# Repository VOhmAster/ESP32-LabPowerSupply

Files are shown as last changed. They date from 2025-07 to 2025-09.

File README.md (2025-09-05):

# ESP32 Lab Power Supply

DIY ESP32-based laboratory power supply with TFT display, rotary encoder, and OTA update.

##  Features
- Dual output (voltage and current control)
- TFT display (TFT_eSPI library)
- Rotary encoder control
- OTA firmware update
- Presets (3.3V, 5V, 7V) and customizable modes
- INA219 current measurement

##  Hardware
- ESP32 DevKit
- ILI9488 TFT display (3.5")
- SM-28BYJ-48-5V stepper motor x 2
- SM-ULN2003 stepper driver x 2
- INA219 current sensor x 2
- Rotary encoder
- LM2596S-PSUM module x 2
- SCT2650-STP-DWN module
- 40 x 40 12V fan

##  Setup
1. Install **ESP32 core** in Arduino IDE.
2. Install required libraries:
   - **TFT_eSPI** (for display)
   - **Adafruit INA219** (for current measurement)
   - **ArduinoOTA** (for OTA updates)
3. **Modify pin assignments in `User_Setup.h`** in the TFT_eSPI library folder to match your hardware configuration.
4. Set up your `User_Setup.h` for TFT.
5. Upload `LabPowerSupply.ino` to ESP32.

##  Recommended Pinout

Here is the recommended pin configuration for the ESP32 Lab Power Supply project. Please adjust the `User_Setup.h` file accordingly.

| Pin | Function | Description |
|---|---|---|
| GPIO 5  | Motor M1_IN1 | Motor driver input 1 for channel 1 |
| GPIO 19 | Motor M1_IN2 | Motor driver input 1 for channel 2 |
| GPIO 27 | Motor M1_IN3 | Motor driver input 1 for channel 3 |
| GPIO 33 | Motor M1_IN4 | Motor driver input 1 for channel 4 |
| GPIO 32 | Motor M2_IN1 | Motor driver input 2 for channel 1 |
| GPIO 25 | Motor M2_IN2 | Motor driver input 2 for channel 2 |
| GPIO 26 | Motor M2_IN3 | Motor driver input 2 for channel 3 |
| GPIO 14 | Motor M2_IN4 | Motor driver input 2 for channel 4 |
| GPIO 12 | Display LED | TFT display LED pin |
| GPIO 15 | Display CS | TFT display chip select |
| GPIO 2  | Display DC | TFT display data/command |
| GPIO 4  | Display RST | TFT display reset |
| GPIO 18 | Display CLK | TFT display clock (SPI SCK) |
| GPIO 23 | Display MOSI | TFT display data line (SPI MOSI) |
| GPIO 34 | Rotary Encoder A  | Rotary encoder signal A |
| GPIO 35 | Rotary Encoder B  | Rotary encoder signal B |
| GPIO 21 | INA219 SDA | INA219 sensor data line (I2C) |
| GPIO 22 | INA219 SCL | INA219 sensor clock line (I2C) |

> **Note:**  
> - This pinout is for the specific configuration used in this project.  
> - Modify the pins in the `User_Setup.h` file to fit your hardware setup.

### Hybrid Control System with Closed-Loop Feedback

This power supply uses a hybrid approach that combines **digital control** and **analog signal measurement**.  
The output voltage and current are continuously monitored through analog readings, while adjustments are performed digitally, resulting in more accurate control compared to systems that rely solely on digital signals.

The system operates with a **closed-loop feedback mechanism**, meaning it always uses the actual measured output values as the basis for regulation.  
This ensures stable and precise voltage and current control under varying load conditions.

### Open-Loop vs Closed-Loop Control

**Open-Loop (Without Feedback):**
Input Setpoint → [ Controller ] → Output  
(No real-time correction based on actual output)

**Closed-Loop (With Feedback):**
Input Setpoint → [ Controller ] → Output → [ Measurement ] → Feedback → [ Controller ]  
(The system continuously adjusts based on the actual measured values)

### Optional Bleeder Resistor for Smoother Voltage Adjustment

For more stable voltage adjustments, especially when fine-tuning the output voltage, it may be useful to add a bleeder resistor to the power supply circuit. This is optional and depends on your specific needs.

**Recommended Value:**
- **1 kΩ / 0.6 W** metal film resistor

## Demo

**Preset Switching:**  
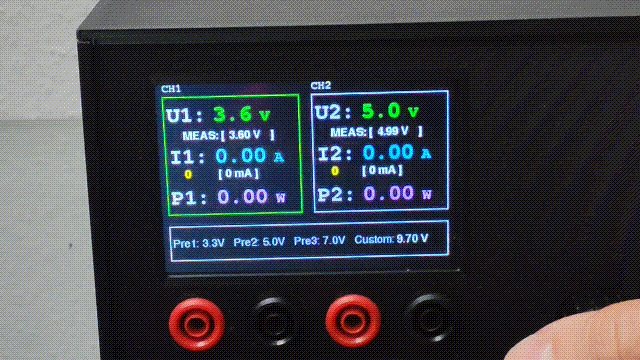
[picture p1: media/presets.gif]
Presets


**Load Response (Closed-loop feedback):**  
Load response

**Boot Sequence:**  
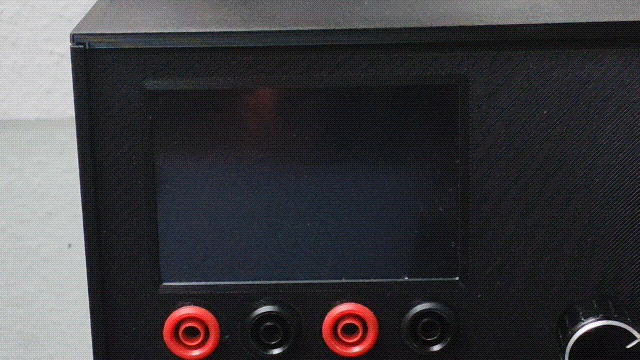
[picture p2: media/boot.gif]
Boot


**OTA Firmware Update:**  
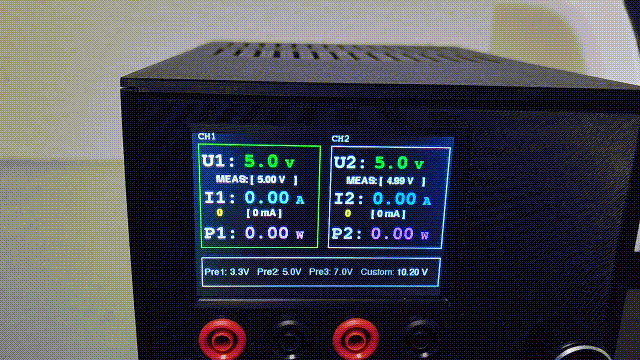
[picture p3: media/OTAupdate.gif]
OTA


I keep improving my projects and sharing everything for free. I really appreciate any support — it helps me buy parts and tools to make even better projects. You can support me here: [Ko-fi](https://ko-fi.com/vohmaster)

**Join my Discord server!**  
Click the invite link below to connect:  
[Discord Invite](https://discord.gg/2u2wJVqS)

## License
This project is licensed under the MIT License - see the [LICENSE](LICENSE) file for details.

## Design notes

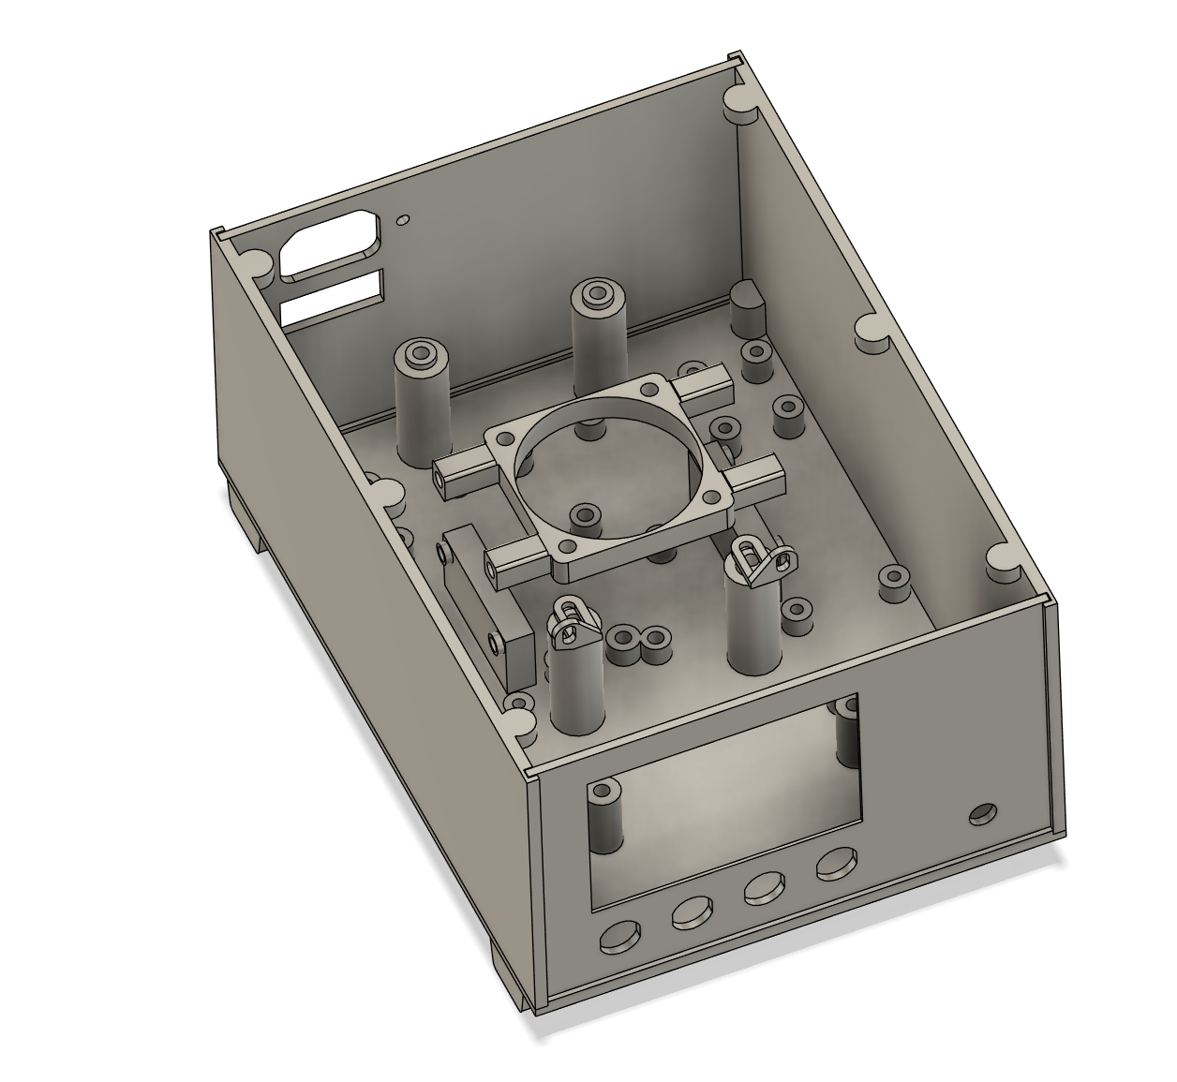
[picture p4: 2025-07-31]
images/Képernyőkép 2025-07-31 165328.png

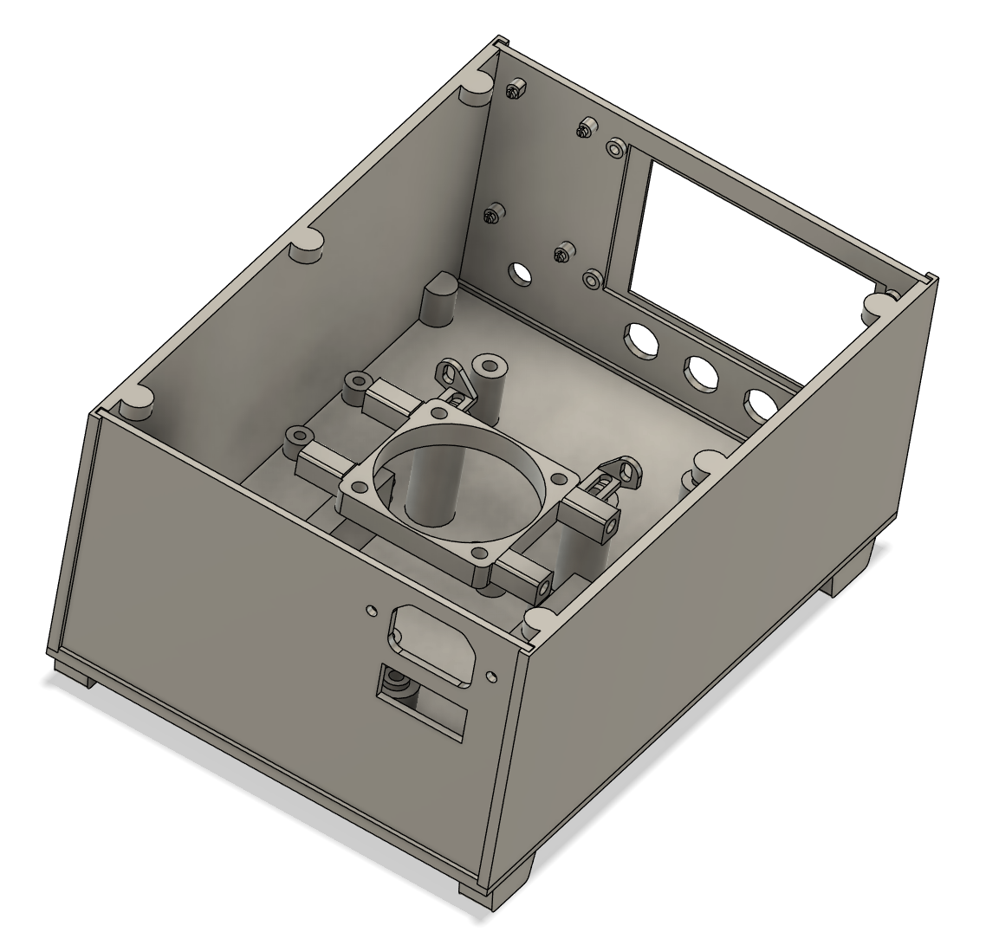
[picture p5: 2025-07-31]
images/Képernyőkép 2025-07-31 165347.png

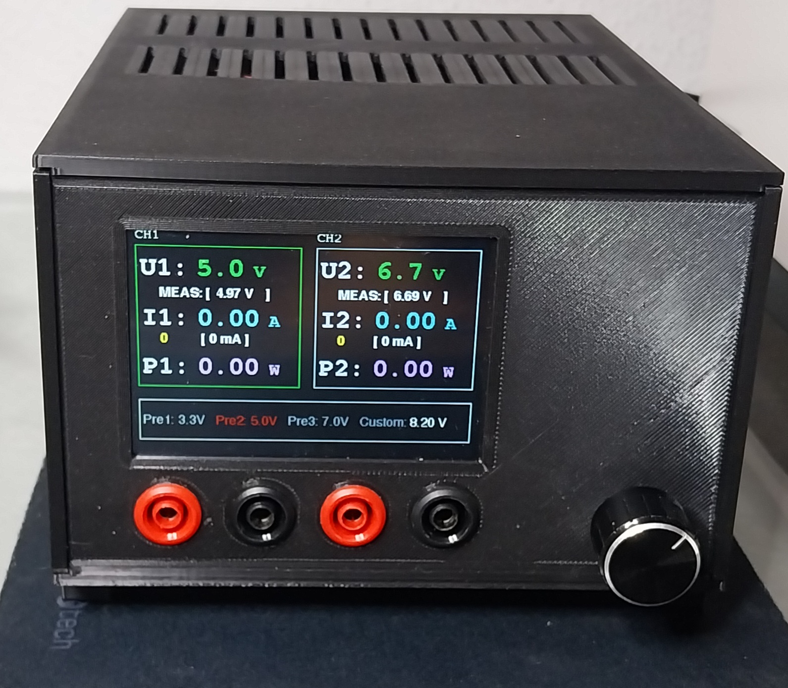
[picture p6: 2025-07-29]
images/labpowersupply.jpg

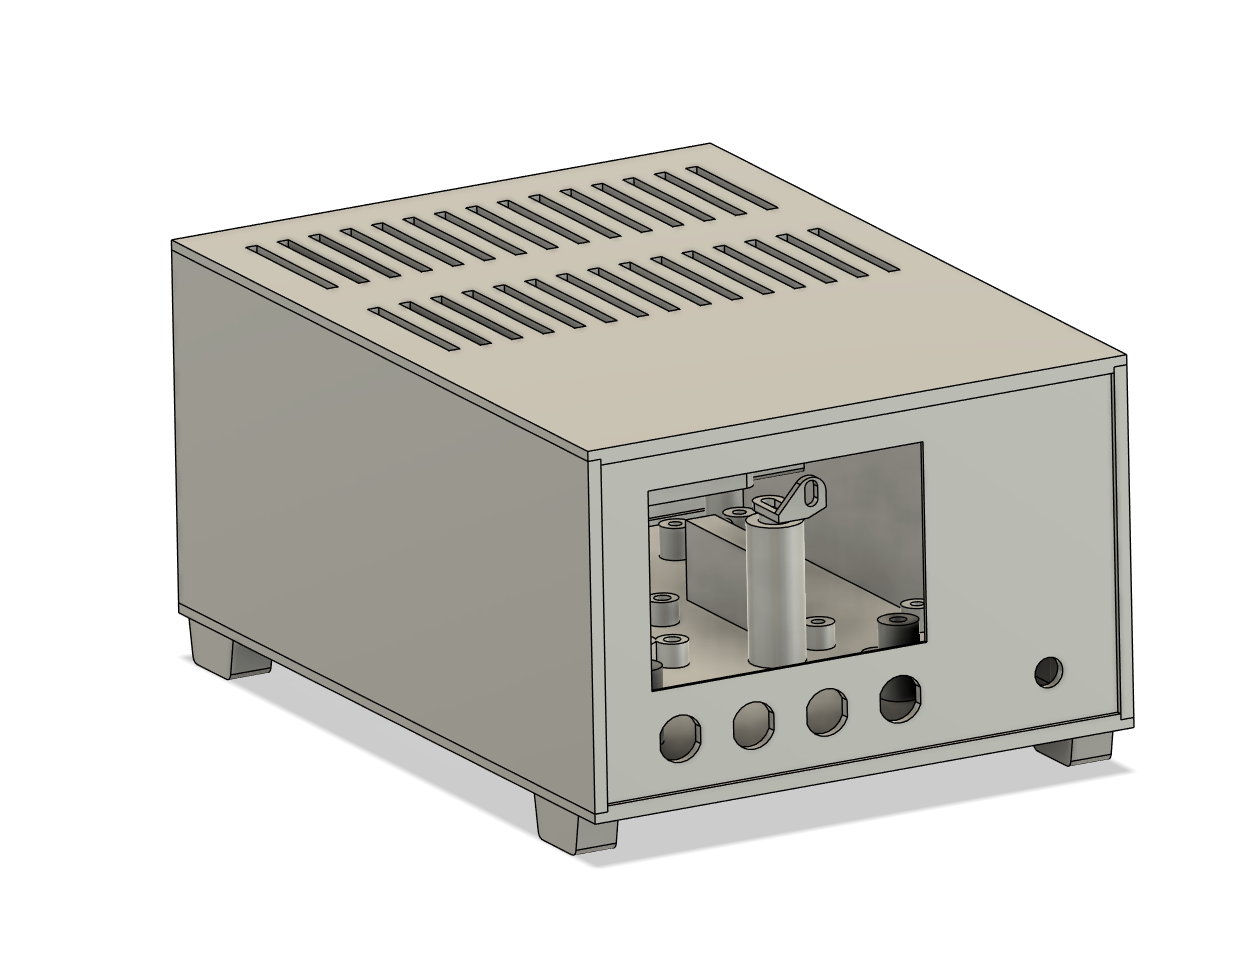
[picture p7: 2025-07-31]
images/Képernyőkép 2025-07-31 165406.png

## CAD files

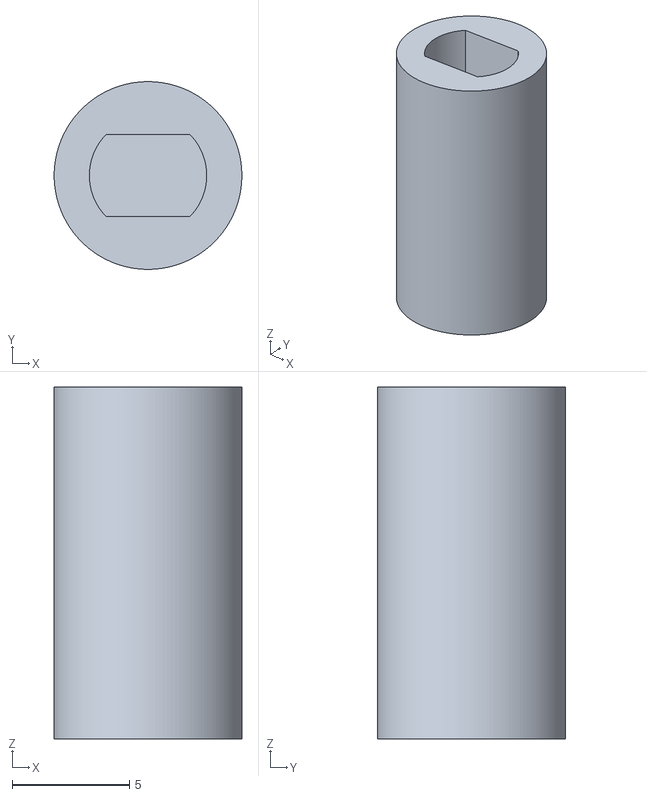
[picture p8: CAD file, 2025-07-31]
3D-models/shaft_coupling.stl
8.00 x 8.00 x 15.0

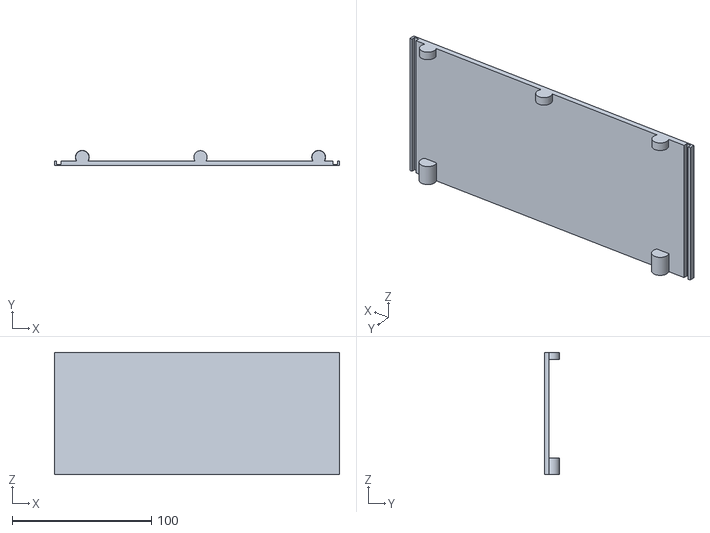
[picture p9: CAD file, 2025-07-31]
3D-models/right_panel.stl
205.0 x 11.0 x 88.0

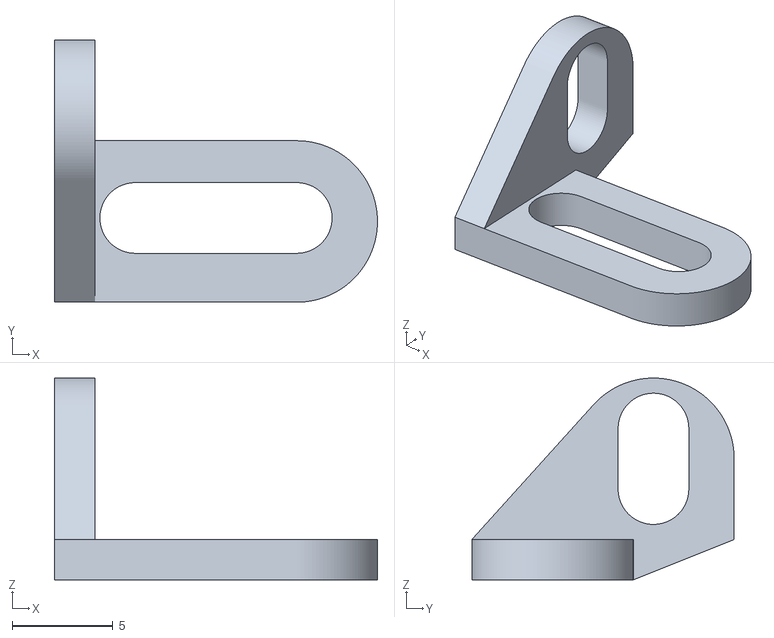
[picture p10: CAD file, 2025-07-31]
3D-models/right_bracket.stl
16.0 x 13.0 x 10.00

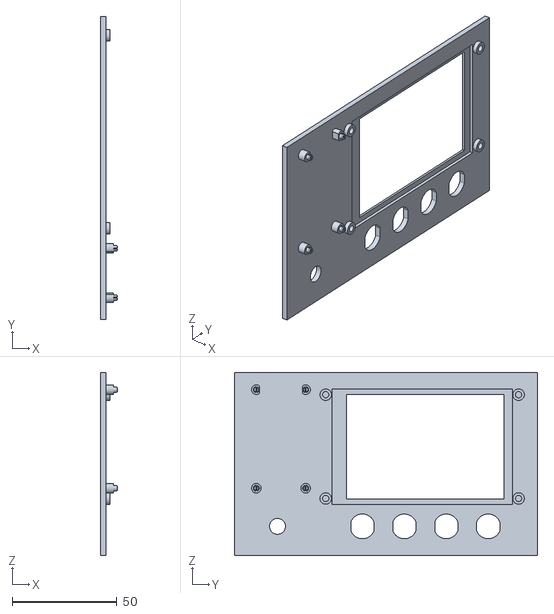
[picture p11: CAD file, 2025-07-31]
3D-models/fornt_panel.stl
7.90 x 144.5 x 87.5

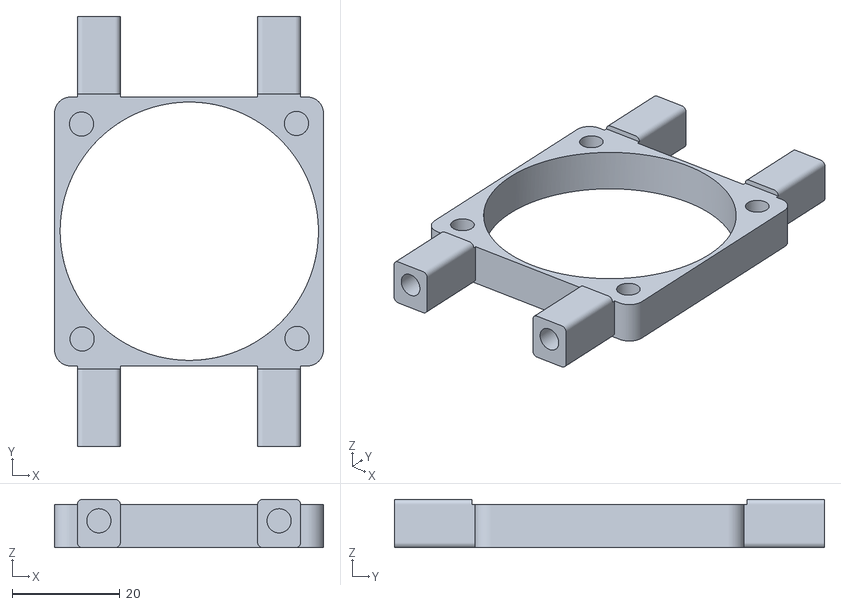
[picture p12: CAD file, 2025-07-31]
3D-models/fan_consol.stl
50.0 x 80.0 x 9.00

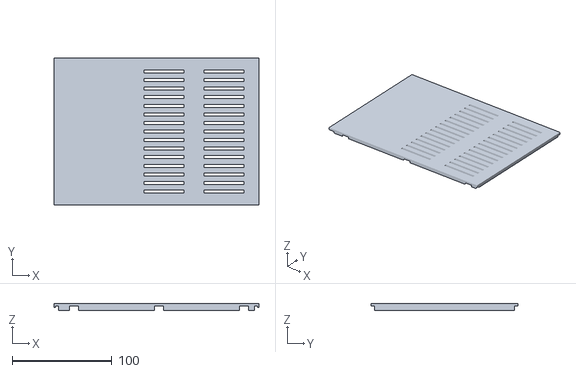
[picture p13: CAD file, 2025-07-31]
3D-models/cover.stl
205.0 x 147.0 x 7.00

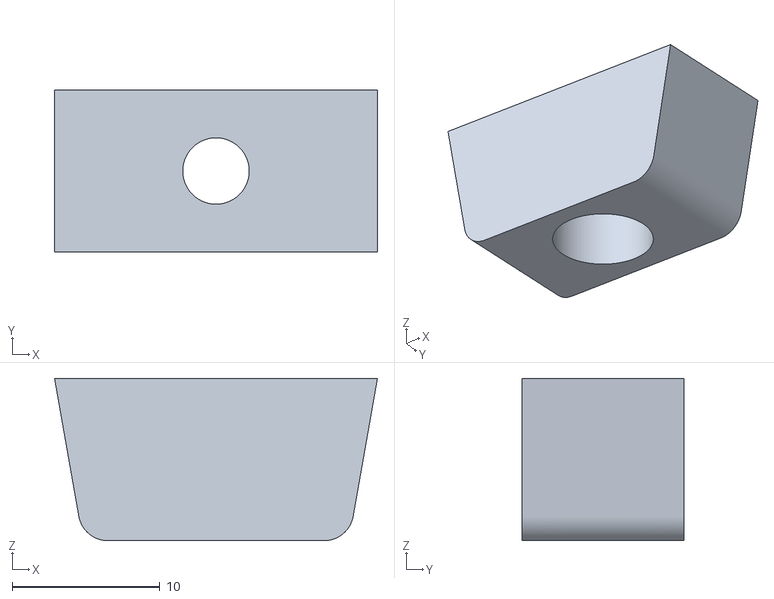
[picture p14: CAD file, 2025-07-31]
3D-models/Casefoot.stl
21.9 x 11.0 x 11.0

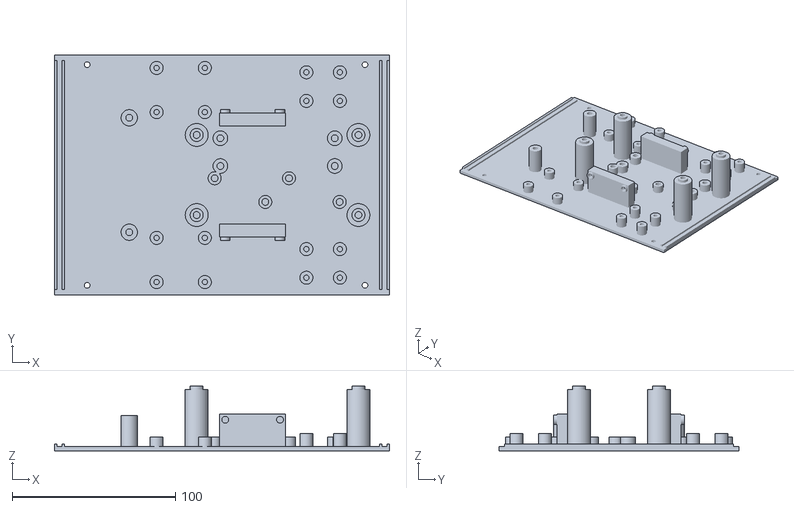
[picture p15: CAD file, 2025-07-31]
3D-models/bottom_panel.stl
205.0 x 147.0 x 39.5

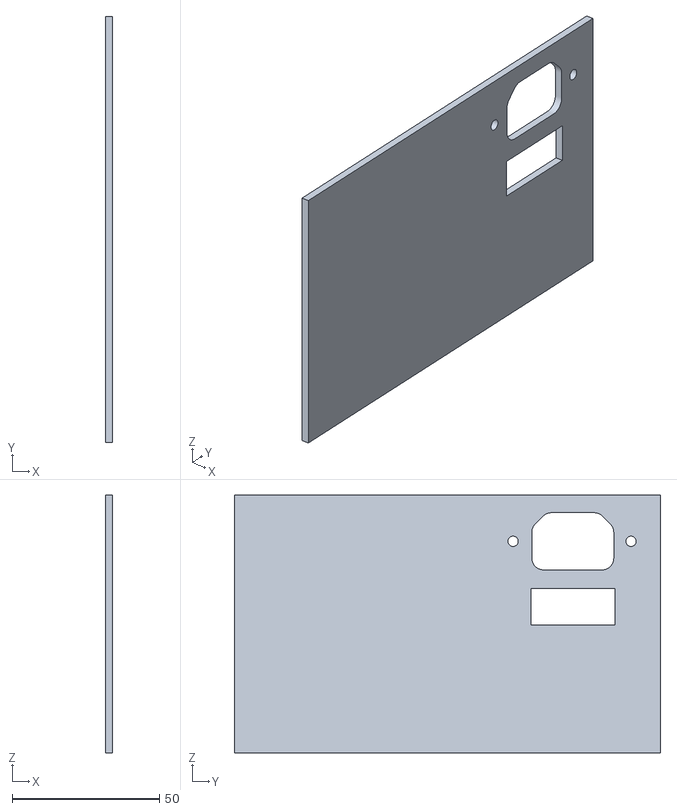
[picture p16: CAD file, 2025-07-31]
3D-models/back_panel.stl
2.50 x 144.5 x 87.5

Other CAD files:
3D-models/left_panel.stl
3D-models/left_bracket.stl

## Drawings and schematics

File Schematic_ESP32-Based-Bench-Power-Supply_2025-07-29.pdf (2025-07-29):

# TFT1 SD_SCK 18 SD_MISO ¹⁷

3 | 4 4V-40V Vin | 1.2V-36V Vout 4

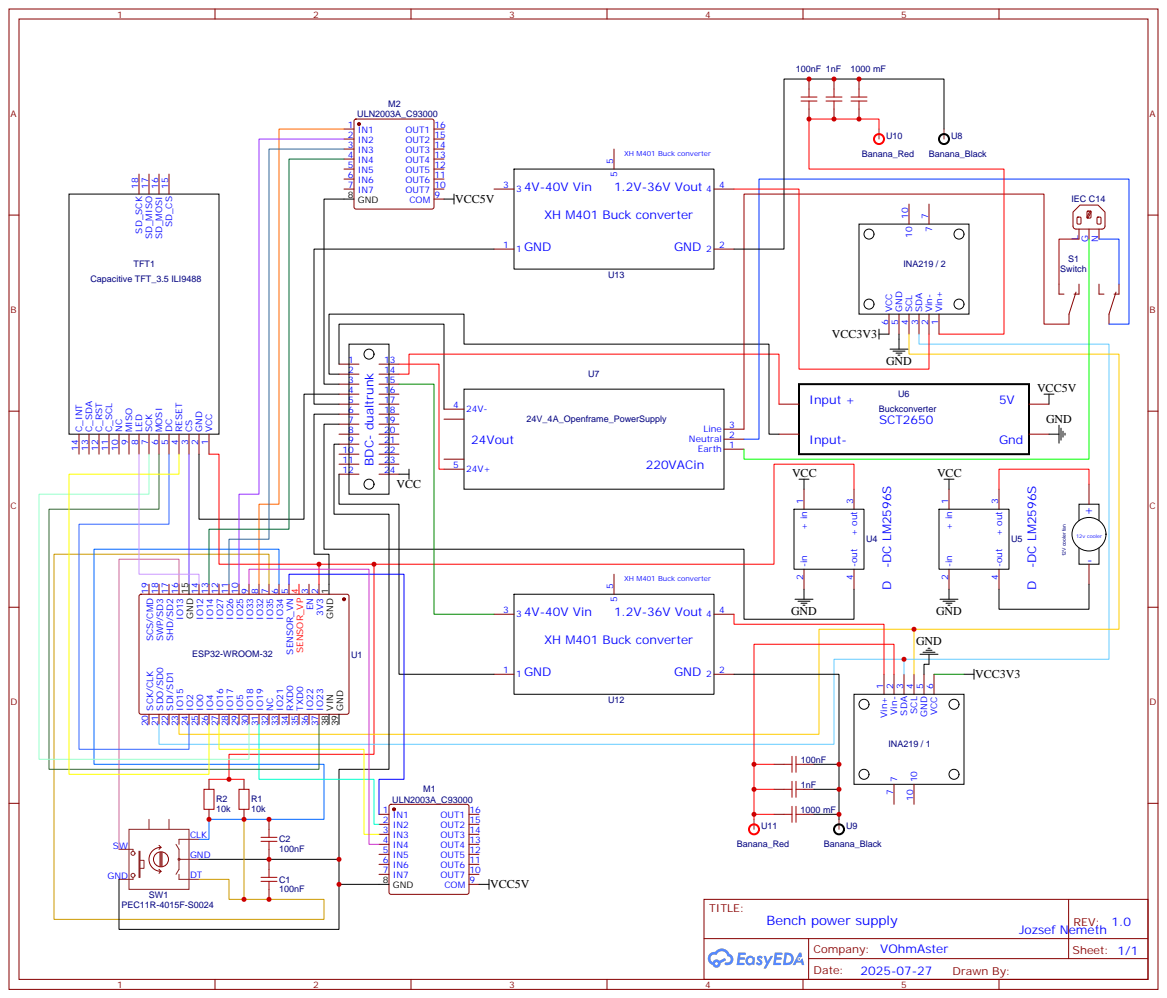
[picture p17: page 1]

9 IO25 10 IO26 11 IO27 12 IO14 13 IO12 14 GND 15 IO13 16 SHD/SD2 17 SWP/SD3 18 SCS/CMD 19 SCK/CLK 20 SDO/SD0 21 SDI/SD1 22 IO15 23 IO2 24 IO0 25 IO4 26 IO16 27 IO17 28 IO5 29 IO18 30

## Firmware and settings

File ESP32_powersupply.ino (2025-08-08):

#include <TFT_eSPI.h>
#include <SPI.h>
#include <ESP32Encoder.h>
#include <WiFi.h>
#include <ArduinoOTA.h>
#include "Free_Fonts.h" 
#include <string>
#include <Adafruit_INA219.h>
#include <Stepper.h>
#include <ESPmDNS.h>.
#include <EEPROM.h>

#define EEPROM_ADDR_PSET 0 

Adafruit_INA219 ina1(0x41);  // Default title
Adafruit_INA219 ina2(0x40);  // Second module with a different title

const char* ssid = "YOUR SSID";
const char* password = "YOUR PASSWORD";

// Variables for button handling
int presetIndex = 0;
bool buttonPressed = false;
unsigned long buttonPressStartTime = 0;
bool longPressHandled = false;
const unsigned long longPressDuration = 500; // Long button press duration
bool longPressMode = false;
bool inCustomPresetMode = false;

// presets
float presetVoltage;
float psetCustom = 0; // Starting value

// Define character color variables
uint16_t BGcolor;
uint16_t StandardColor;
uint16_t Out1Volt;
uint16_t Out2Volt;
uint16_t Out1Amper;
uint16_t Out2Amper;
uint16_t Out1Watt;
uint16_t Out2Watt;
uint16_t PsetI;
uint16_t PsetA;

TFT_eSPI tft = TFT_eSPI();

#define CLK 34
#define DT 35
#define SW  13
#define TFT_LED_PIN 12 

#define STEPS_PER_REV 2048
// Motor 1
#define M1_IN1 5
#define M1_IN2 19
#define M1_IN3 27
#define M1_IN4 33

// Motor 2
#define M2_IN1 32
#define M2_IN2 25
#define M2_IN3 26
#define M2_IN4 14

Stepper stepper1(STEPS_PER_REV, M1_IN1, M1_IN3, M1_IN2, M1_IN4);
Stepper stepper2(STEPS_PER_REV, M2_IN1, M2_IN3, M2_IN2, M2_IN4);

float value_U1 = 5;
float value_U2 = 5;

float globalOutV1 = 5;
float globalOutV2 = 5;

ESP32Encoder encoder;

float value = 2.5;
const float minValue = 1.5;
const float maxValue = 20.0;
const float step = 0.1;

long LastEncoderCount = 0;

unsigned long lastEncoderCheck = 0;
const unsigned long encoderInterval = 200;  // ms

unsigned long lastMeasurementTime = 0;
const unsigned long measurementInterval = 500; //ms

//float lastDisplayedValue = -1;
int voltageState = 1;

// Position of text lines
  int ULine = 60;
  int ILine = 130;
  int PLine = 200;

  int xs1pos = 15;
  int xs2pos = 255;
  int yspos = 20;
  int borderW = 220;

// Position of the preset menu

  int PrXpos = 15;
  int PrYpos = 240;


void setup() {
  delay(1000);
  Wire.begin();  
  Wire.setClock(400000);  
  Serial.begin(115200);

  EEPROM.begin(512);  

   float value;
  EEPROM.get(EEPROM_ADDR_PSET, value);
  if (value < 1.5 || value > 20.0) value = 2.5;
  psetCustom = value;

  pinMode(TFT_LED_PIN, OUTPUT);
  digitalWrite(TFT_LED_PIN, HIGH); 

  tft.init();
  tft.setRotation(1);

  // OUTPUT warning
  tft.fillScreen(BGcolor);
  tft.setCursor(10, 30);
  tft.setFreeFont(FF21);
  tft.setTextColor(TFT_YELLOW, BGcolor);
  tft.print("OUTPUT ACTIVE");
  tft.setCursor(10, 70);
  tft.print("WAIT FOR READY...");
  
  tft.setCursor(10, 110);   
  tft.setFreeFont(FM12);  
  tft.setTextColor(TFT_WHITE, BGcolor);  
  tft.print("Connection to WiFi");

  WiFi.begin(ssid, password);
  delay(500);

  unsigned long startAttemptTime = millis();  

int XDot = 10;
while (WiFi.status() != WL_CONNECTED && millis() - startAttemptTime < 10000) { 
  delay(500);
  Serial.print(".");
  tft.setCursor(XDot, 140);
  XDot += 12;
  tft.print(".");
}

if (WiFi.status() == WL_CONNECTED) {
 
  tft.setCursor(10, 170);
  tft.print("WiFi connected!");
  delay(2000);
  setupOTA();  
} else {
  
  tft.setCursor(10, 170);
  tft.print("WiFi connection failed!");
  tft.setCursor(10, 200);
  tft.print("Continuing without OTA...");
  delay(2000);
}
    
  tft.setFreeFont(FM12);
if (!ina1.begin()) {
  
  tft.setCursor(10, 240);
  tft.setTextColor(TFT_RED); 
  tft.print("INA219 #1 not detected!");
  delay(2000);
  while (1);
} else {
  
  tft.setCursor(10, 240);
  tft.setTextColor(TFT_GREEN); 
  tft.print("INA219 #1 detected.");
  delay(2000);
}
ina1.setCalibration_32V_2A();

if (!ina2.begin()) {
 
  tft.setCursor(10, 280);
  tft.setTextColor(TFT_RED);
  tft.print("INA219 #2 not detected!");
  delay(2000);
  while (1);
} else {
  tft.setCursor(10, 280);
  tft.setTextColor(TFT_GREEN);
  tft.print("INA219 #2 detected.");
  delay(2000);
}
ina2.setCalibration_32V_2A();
  
  stepper1.setSpeed(8);
  stepper2.setSpeed(8);

   
  pinMode(SW, INPUT_PULLUP);

  encoder.attachHalfQuad(DT, CLK);
      
    // Color definitions
 
BGcolor = tft.color565(0, 0, 0);
StandardColor = tft.color565(232, 228, 227);
Out1Volt= tft.color565(65, 227, 20);
Out2Volt= tft.color565(65, 227, 20);
Out1Amper= tft.color565(158, 230, 226);
Out2Amper= tft.color565(158, 230, 226);
Out1Watt= tft.color565(237, 161, 232);
Out2Watt= tft.color565(237, 161, 232);
PsetI= tft.color565(171, 168, 167);
PsetA= tft.color565(217, 23, 9);


// Font definitions

#define StandardFont &FreeMonoBold18pt7b
#define measText &FreeMonoBold12pt7b

  tft.fillScreen(BGcolor);
  
  // Menu structure setup

  tft.setCursor(xs1pos, 10);   
  tft.setFreeFont(FM9);  
  tft.setTextColor(TFT_WHITE, BGcolor);  
  tft.print("CH1");
  tft.setCursor(xs2pos, 10);
  tft.print("CH2");
   
  // Left and right frame
  tft.drawRect(xs1pos, yspos, borderW, 200, TFT_GREEN);
  tft.drawRect(xs2pos, yspos, borderW, 200, TFT_WHITE);

 // Preset menu frame
   tft.drawRect(PrXpos, PrYpos, 460, 60, TFT_WHITE);

 // Preset texts
  tft.setCursor(PrXpos + 5, PrYpos +35);   
  tft.setFreeFont(FSS9);  
  tft.setTextColor(PsetI, BGcolor);  
  tft.print("Pre1: 3.3V   ");
  tft.print("Pre2: 5.0V   ");
  tft.print("Pre3: 7.0V   ");
  tft.print("Custom:");
  char bufferSet[20];
  sprintf(bufferSet, "%.2f V", psetCustom);
  tft.setCursor(PrXpos + 375, PrYpos + 35);   
  tft.setFreeFont(FSS9);  
  tft.setTextColor(TFT_WHITE, BGcolor);  
  tft.print(bufferSet);

  
voltageState = 1;
while (abs(ina1.getBusVoltage_V() - globalOutV1) > 0.05) {
  regulateOutputVoltageCH1();
  delay(2); 
}
drawVoltage(value_U1);

voltageState = 2;
while (abs(ina2.getBusVoltage_V() - globalOutV2) > 0.05) {
  regulateOutputVoltageCH2();
  delay(2); 
}
drawVoltage(value_U2);

encoder.setCount((int)(value_U1 / step) * 2);
voltageState = 1;

    tft.setFreeFont(FF21);
    tft.setTextColor(TFT_WHITE, BGcolor);
    tft.setCursor(xs1pos+30, ULine + 30);
    tft.print("MEAS: [               ]");
    tft.setCursor(xs2pos+30, ULine + 30);
    tft.print("MEAS: [               ]");

}

void setupOTA() {
  ArduinoOTA.setHostname("esp32-tap");
  static std::string Oldpercent = "";

  ArduinoOTA.onStart([]() {
    tft.fillScreen(BGcolor); 
    tft.setFreeFont(FF21);
    tft.setTextColor(StandardColor, BGcolor);
    tft.setCursor(10, 30);
    tft.print("OTA: update starting...");
  });

  ArduinoOTA.onProgress([](unsigned int progress, unsigned int total) {
    char buffer[32];
    tft.setCursor(10, 80);
    tft.setFreeFont(FF18);
    tft.print("Progress :");
    sprintf(buffer, "%3u %%", (progress * 100) / total);
    tft.setCursor(105, 80);
    tft.setTextColor(TFT_BLACK, BGcolor);
    tft.print(Oldpercent.c_str());
    tft.setCursor(105, 80);
    tft.setTextColor(TFT_LIGHTGREY, BGcolor);
    tft.print(buffer);

    Oldpercent = std::string(buffer);
  });

  ArduinoOTA.onEnd([]() {
    tft.fillRect(0, 90, 480, 40, BGcolor);
    tft.setCursor(10, 120);
    tft.setFreeFont(FF21);
    tft.setTextColor(TFT_GREEN, BGcolor);
    tft.print("Update complete.");
  });

  ArduinoOTA.onError([](ota_error_t error) {
    tft.fillRect(0, 90, 480, 60, BGcolor);
    tft.setCursor(10, 120);
    tft.setFreeFont(FF21);
    tft.setTextColor(TFT_RED, BGcolor);
    tft.print("OTA hiba: ");
    switch (error) {
      case OTA_AUTH_ERROR: tft.print("Auth"); break;
      case OTA_BEGIN_ERROR: tft.print("Begin"); break;
      case OTA_CONNECT_ERROR: tft.print("Connect"); break;
      case OTA_RECEIVE_ERROR: tft.print("Receive"); break;
      case OTA_END_ERROR: tft.print("End"); break;
      default: tft.print("Unknown"); break;
    }
  });

  ArduinoOTA.begin();
}

void loop() {
  unsigned long currentTime = millis();

  if (currentTime - lastMeasurementTime >= measurementInterval) {
    lastMeasurementTime = currentTime;
    drawMeasuredVoltage(); 
    drawAmper();
    drawWatt();
  }

 

    // Only handle the encoder and short press in normal mode
  if (!longPressMode) {

    // Select active voltage variable (with reference)
    float& activeValue = (voltageState == 1) ? value_U1 : value_U2;

   // Get raw encoder value (interpreted as step count)
    int encSteps = encoder.getCount() / 2;
    float newValue = encSteps * step;

    // Handle boundaries
    if (newValue < minValue) {
        newValue = minValue;
        encoder.setCount((int)(minValue / step) * 2);
    } else if (newValue > maxValue) {
        newValue = maxValue;
        encoder.setCount((int)(maxValue / step) * 2);
    }

    activeValue = newValue;
    drawVoltage(activeValue);
}

 unsigned long currentMillis = millis();
  if (currentMillis - lastEncoderCheck >= encoderInterval) {
    lastEncoderCheck = currentMillis;

    
    int buttonState = digitalRead(SW);

    if (buttonState == LOW) {
      if (!buttonPressed) {
        buttonPressed = true;
        buttonPressStartTime = currentMillis;
        longPressHandled = false;
      } else {
        if (!longPressHandled && (currentMillis - buttonPressStartTime >= longPressDuration)) {
          longPressHandled = true;
          longPressMode = !longPressMode; 
          if (longPressMode) {
             inCustomPresetMode = false;
             presetIndex = 0;  
            applyPreset(presetIndex);
            drawPresetMenu(presetIndex);

          } else {
            exitLongPressMode();

          }
        }
      }
    } else {
      if (buttonPressed) {
        if (!longPressHandled && !longPressMode) {
          voltageState = (voltageState == 1) ? 2 : 1;
          float encoderValue = (voltageState == 1) ? value_U1 : value_U2;
          encoder.setCount((int)(encoderValue / step) * 2);

      if (voltageState == 1) {
        // Change frame colors to the active channel
        tft.drawRect(xs1pos, yspos, borderW, 200, TFT_GREEN);  
        tft.drawRect(xs2pos, yspos, borderW, 200, TFT_WHITE);  
      } else {
        
        tft.drawRect(xs1pos, yspos, borderW, 200, TFT_WHITE);  
        tft.drawRect(xs2pos, yspos, borderW, 200, TFT_GREEN);  
      }


        }
        buttonPressed = false;
      }
    }
  }

  if (longPressMode) {
  if (inCustomPresetMode) {
    handleCustomPreset(); 
  } else {
    handleLongPressMode(); 
  }
}

  regulateOutputVoltageCH1();
  regulateOutputVoltageCH2();
  ArduinoOTA.handle();
}


void enterLongPressMode() {
  
  // Entered long press mode
 
  tft.drawRect(PrXpos, PrYpos, 460, 60, TFT_GREEN);
  presetIndex = 0;
  applyPreset(presetIndex);
  
}

void exitLongPressMode() {
  encoder.attachHalfQuad(DT, CLK);
  encoder.setCount(LastEncoderCount * 2);   
  // Exited long press mode
  // Redraw preset bar with inactive color
  tft.setCursor(PrXpos + 5, PrYpos + 35);   
  tft.setFreeFont(FSS9);  

  tft.setTextColor(PsetI, BGcolor);  
  tft.print("Pre1: 3.3V   ");

  tft.setTextColor(PsetI, BGcolor);  
  tft.print("Pre2: 5.0V   ");

  tft.setTextColor(PsetI, BGcolor);  
  tft.print("Pre3: 7.0V   ");

  tft.setTextColor(PsetI, BGcolor);  
  tft.print("Custom:");

  tft.drawRect(PrXpos, PrYpos, 460, 60, TFT_WHITE);
  if (voltageState == 1){
    globalOutV1 = presetVoltage;
  tft.drawRect(xs2pos, yspos, borderW, 200, TFT_WHITE); 
  tft.drawRect(xs1pos, yspos, borderW, 200, TFT_GREEN); 
   
  }else{
     globalOutV2 = presetVoltage;
  tft.drawRect(xs1pos, yspos, borderW, 200, TFT_WHITE); 
  tft.drawRect(xs2pos, yspos, borderW, 200, TFT_GREEN); 
   
   }
  drawVoltage(presetVoltage);
  
  }

void handleLongPressMode() {
  
  if (inCustomPresetMode) {
    handleCustomPreset();
    return;  
  }

  int buttonState = digitalRead(SW);
  encoder.detach(); 
  if (buttonState == LOW) {
  if (!buttonPressed) {
    buttonPressed = true;
    buttonPressStartTime = millis();
    longPressHandled = false;
  }
} else {
  if (buttonPressed) {
    unsigned long pressDuration = millis() - buttonPressStartTime;
    if (pressDuration < longPressDuration) {
      // Switch preset on button press

      presetIndex = (presetIndex + 1) % 4;

      if (presetIndex == 3) {
        inCustomPresetMode = true;
        drawPresetMenu(3);
      } else {
        inCustomPresetMode = false;
        applyPreset(presetIndex);
        drawPresetMenu(presetIndex);
      }
    }
    buttonPressed = false;
  }
}
}

void drawPresetMenu(int activeIndex) {
  tft.setCursor(PrXpos + 5, PrYpos + 35);
  tft.setFreeFont(FSS9);

  for (int i = 0; i < 4; i++) {
    if (i == activeIndex) {
      tft.setTextColor(PsetA, BGcolor);  // Active color
    } else {
      tft.setTextColor(PsetI, BGcolor);  // Inactive color
    }

    switch (i) {
      case 0:
        tft.print("Pre1: 3.3V   ");
        break;
      case 1:
        tft.print("Pre2: 5.0V   ");
        break;
      case 2:
        tft.print("Pre3: 7.0V   ");
        break;
      case 3:
        tft.print("Custom:");
        break;
    }
  }
}

void applyPreset(int index) {
       encoder.detach(); 
  switch (index) {
    case 0:
      presetVoltage = 3.3;
      LastEncoderCount = 33;
     break;
    case 1:
      presetVoltage = 5.0;
      LastEncoderCount = 50;
      break;
    case 2:
      presetVoltage = 7.0;
      LastEncoderCount = 70;
      break;
    default:
      
      presetVoltage = psetCustom; 
      LastEncoderCount = psetCustom * 10;
      break;  
  }

 // Set the voltage value to the corresponding channel
  if (voltageState == 1) {
    globalOutV1 = presetVoltage;
  } else {
    globalOutV2 = presetVoltage;
  }
  drawVoltage(presetVoltage);
}

void handleCustomPreset() {
  encoder.attachHalfQuad(DT, CLK);
  static long lastCount = 0;
  static bool initialized = false;
  static std::string OldpsetCustom = "";

  if (!initialized) {
  initialized = true;

  // psetCustom retrieved from EEPROM has already been set previously

  long rawCount = (psetCustom) / 0.1;
  //Limits of adjustment with the encoder.

  if (rawCount < 15) rawCount = 15; // 15 = 1.5V
  else if (rawCount > 200) rawCount = 200; // 200 = 20V

  encoder.setCount(rawCount * 2); 
  lastCount = rawCount;

  if (voltageState == 1) {
    globalOutV1 = psetCustom;
  } else {
    globalOutV2 = psetCustom;
  }

  
  char bufferSet[20];
  sprintf(bufferSet, "%.2f V", psetCustom);
  tft.setCursor(PrXpos + 375, PrYpos + 35);   
  tft.setFreeFont(FSS9);  
  tft.setTextColor(TFT_WHITE, BGcolor);  
  tft.print(bufferSet);
  OldpsetCustom = std::string(bufferSet);

  drawVoltage(psetCustom);
}
   //Limits of adjustment with the encoder.

  long rawCount = encoder.getCount() / 2;

   if (rawCount < 15) {  // 15 = 1.5V
    rawCount = 15;
    encoder.setCount(15 * 2);
  } else if (rawCount > 200) {  // 200 = 20V
    rawCount = 200;
    encoder.setCount(200  * 2);
  }

  long currentCount = rawCount;

   if (currentCount != lastCount) {
    lastCount = currentCount;
    psetCustom = 0 + currentCount * 0.1;

     if (voltageState == 1) {
      globalOutV1 = psetCustom;
    } else {
      globalOutV2 = psetCustom;
    }

    char bufferSet[20];
    sprintf(bufferSet, "%.2f V", psetCustom);

    if (OldpsetCustom != std::string(bufferSet)) {
      tft.setCursor(PrXpos + 375, PrYpos + 35);   
      tft.setFreeFont(FSS9);  
      tft.setTextColor(BGcolor, BGcolor);  
      tft.print(OldpsetCustom.c_str());

      tft.setCursor(PrXpos + 375, PrYpos + 35);   
      tft.setFreeFont(FSS9);  
      tft.setTextColor(TFT_WHITE, BGcolor);  
      tft.print(bufferSet);

      OldpsetCustom = std::string(bufferSet);
    }
    
    drawVoltage(psetCustom);
    
  }

  int buttonState = digitalRead(SW);
  
  if (buttonState == LOW) {
    float lastSavedValue;
    EEPROM.get(EEPROM_ADDR_PSET, lastSavedValue);
    

    if (!isnan(psetCustom) && !isnan(lastSavedValue)) {
      if (fabs(lastSavedValue - psetCustom) > 0.05) {
        EEPROM.put(EEPROM_ADDR_PSET, psetCustom);
        EEPROM.commit();
        LastEncoderCount = psetCustom * 10;
        
      }
    }

    inCustomPresetMode = false;  
    
    presetIndex = -1;
    applyPreset(presetIndex);  
    initialized = false;
  }
}



void drawMeasuredVoltage() {
  static std::string OldRealV1 = "";
  static std::string OldRealV2 = "";

  float realV1 = ina1.getBusVoltage_V(); // U1
  float realV2 = ina2.getBusVoltage_V(); //U2

  char bufferSet[20];

  const float epsilon = 0.01;  
// --- U1 measured ---

  sprintf(bufferSet,  "%.2f V ", realV1);
  if (fabs(realV1 - atof(OldRealV1.c_str())) > epsilon) {  
    
    tft.setCursor(xs1pos+105, ULine + 30);
    tft.setFreeFont(FF21);
    tft.setTextColor(BGcolor, BGcolor);
    tft.print(OldRealV1.c_str());

    // New value

    tft.setCursor(xs1pos+105, ULine + 30);
    tft.setFreeFont(FF21);
    tft.setTextColor(TFT_WHITE, BGcolor);  
    tft.print(bufferSet);

    OldRealV1 = std::string(bufferSet);
  }

 // --- U2 measured ---
  
  sprintf(bufferSet, "%.2f V ", realV2);
  if (fabs(realV2 - atof(OldRealV2.c_str())) > epsilon) {  
    
    tft.setCursor(xs2pos+105, ULine + 30);
    tft.setFreeFont(FF21);
    tft.setTextColor(BGcolor, BGcolor);
    tft.print(OldRealV2.c_str());

   // New value
    
    tft.setCursor(xs2pos+105, ULine + 30);
    tft.setFreeFont(FF21);
    tft.setTextColor(TFT_WHITE, BGcolor);
    tft.print(bufferSet);

    OldRealV2 = std::string(bufferSet);
  }
}


void drawVoltage(float voltage) {
  static std::string OldVoltage1 = "";
  static std::string OldVoltage2 = "";
  char bufferSet[10];
  sprintf(bufferSet, "%.1f", voltage);

  if (voltageState == 1) {
    if (OldVoltage1 != std::string(bufferSet)) {
     
      tft.setCursor(xs1pos + 80, ULine);
      tft.setFreeFont(StandardFont);
      tft.setTextColor(BGcolor, BGcolor);
      tft.print(OldVoltage1.c_str());
      tft.setFreeFont(measText);
      tft.print(" V");

      // Draw new value

      tft.setCursor(xs1pos + 6, ULine);
      tft.setFreeFont(StandardFont);
      tft.setTextColor(StandardColor, BGcolor);
      tft.print("U1: ");
      tft.setCursor(xs1pos + 80, ULine);
      tft.setTextColor(Out1Volt, BGcolor);
      tft.print(bufferSet);
      tft.setFreeFont(measText);
      tft.print(" V");

      OldVoltage1 = std::string(bufferSet);
      globalOutV1 = voltage;
    }
  } else {
    if (OldVoltage2 != std::string(bufferSet)) {
     
      tft.setCursor(xs2pos + 80, ULine);
      tft.setFreeFont(StandardFont);
      tft.setTextColor(BGcolor, BGcolor);
      tft.print(OldVoltage2.c_str());
      tft.setFreeFont(measText);
      tft.print(" V");

      // Draw new value

      tft.setCursor(xs2pos + 6, ULine);
      tft.setFreeFont(StandardFont);
      tft.setTextColor(StandardColor, BGcolor);
      tft.print("U2: ");
      tft.setCursor(xs2pos + 80, ULine);
      tft.setTextColor(Out2Volt, BGcolor);
      tft.print(bufferSet);
      tft.setFreeFont(measText);
      tft.print(" V");

      OldVoltage2 = std::string(bufferSet);
      globalOutV2 = voltage;
    }
  }
}


/* This code performs feedback control for regulating the output voltages across the channels.
 It reads the measured voltage, applies a moving average filter to smooth the signal, 
 and compares it with the target voltage. If the difference exceeds the specified tolerance, 
 the stepper motor is adjusted to bring the voltage closer to the target.
The `stepInterval` ensures that adjustments happen at fixed intervals, preventing excessive motor movements.
*/
//==============================================================================
void regulateOutputVoltageCH1() {
  static unsigned long lastStepTime = 0;
  static float voltageFiltered1 = 0;
  float readVoltage = ina1.getBusVoltage_V();
  float targetVoltage = globalOutV1;

  // Filtering: moving average style (0.9 weight = slow, stable)
  voltageFiltered1 = 0.9 * voltageFiltered1 + 0.1 * readVoltage;

  // Set the tolerance value for voltage difference. If the measured voltage differs from the target by more than this value, adjustment is made.
  // A smaller tolerance results in finer control and more frequent adjustments.
  const float tolerance = 0.03; 
  // Defines the time interval (in milliseconds) between each step. 
  // The stepper motor will only step if this interval has passed since the last step.
  const unsigned long stepInterval = 10; 

  if (millis() - lastStepTime > stepInterval) {
    float diff = voltageFiltered1 - targetVoltage;

    if (abs(diff) > tolerance) {
      int direction = (diff > 0) ? 1 : -1;
      stepper1.step(direction);
    }

    lastStepTime = millis();
  }
}


void regulateOutputVoltageCH2() {
  static unsigned long lastStepTime = 0;
  static float voltageFiltered2 = 0;
  float readVoltage = ina2.getBusVoltage_V();
  float targetVoltage = globalOutV2;

  // Filtering: moving average style (0.9 weight = slow, stable)
  voltageFiltered2 = 0.9 * voltageFiltered2 + 0.1 * readVoltage;

  // Set the tolerance value for voltage difference. If the measured voltage differs from the target by more than this value, adjustment is made.
  // A smaller tolerance results in finer control and more frequent adjustments.
  const float tolerance = 0.03; 
  // Defines the time interval (in milliseconds) between each step. 
  // The stepper motor will only step if this interval has passed since the last step.
  const unsigned long stepInterval = 10; 

  if (millis() - lastStepTime > stepInterval) {
    float diff = voltageFiltered2 - targetVoltage;

    if (abs(diff) > tolerance) {
      int direction = (diff > 0) ? 1 : -1;
      stepper2.step(direction);
  
    }

    lastStepTime = millis();
  }
}

// =====================================================================


void drawAmper() {
  static std::string OldAmper1 = "";
  static std::string OldAmper2 = "";
  static std::string OldmA1 = "";
  static std::string OldmA2 = "";

static float maxAmper1_mA = 0;
static float maxAmper2_mA = 0;
static std::string OldMaxmA1 = "";
static std::string OldMaxmA2 = "";
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

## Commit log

2025-07-29 Add files via upload
    Add schematic diagram
2025-07-31 Screenshot 3 - Housing and Layout:
    This view focuses on the housing layout, displaying the arrangement and positioning of various elements within the casing.
2025-07-31 Screenshot
    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
2025-08-03 Delete ESP32_labortap.ino
    The previous file labortap.ino has been removed and replaced with ESP32_powersupply.ino for better clarity and maintainability.
    What changed?
    All comments were translated into English for improved readability and accessibility.
    The file was renamed to better represent the purpose of the project.
    Minor code adjustments and clean-up were made to enhance structure and consistency.
    Why the change?
    This update makes the codebase easier to understand for a wider audience, aligns naming conventions with the project’s focus, and ensures that future contributions can be managed more effectively.
2025-08-03 ESP32_powersupply.ino
    - Translated all comments to English for better readability and accessibility
    - Renamed the main file to better represent the project's purpose
    - Made minor code improvements and clean-up for improved consistency
2025-08-03 Update README.md
    Add optional bleeder resistor recommendation for smoother voltage adjustment
2025-08-07 Update ESP32_powersupply.ino
    Improve encoder accuracy using half-quadrature mode and hardware debouncing
2025-08-08 Update ESP32_powersupply.ino
    Setting a more stable measurement algorithm, minor improvements.
